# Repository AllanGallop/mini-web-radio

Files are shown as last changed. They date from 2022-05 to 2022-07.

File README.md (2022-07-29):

# Mini Web Radio

> Builders Guide now available on [Instructables](https://www.instructables.com/Mini-Web-Radio-ESP32/) !

Originally designed as a charity project, the MWR is a simple single-station battery powered internet radio. The design features a combined power-volume dial and 3.5mm headphone socket, utilising a 3D printed case and is based around:

* WeMos Lolin32 Lite (ESP32)
* MAX98357A I2S Dac Amplifier
* 18650 Lithium Battery

</br>

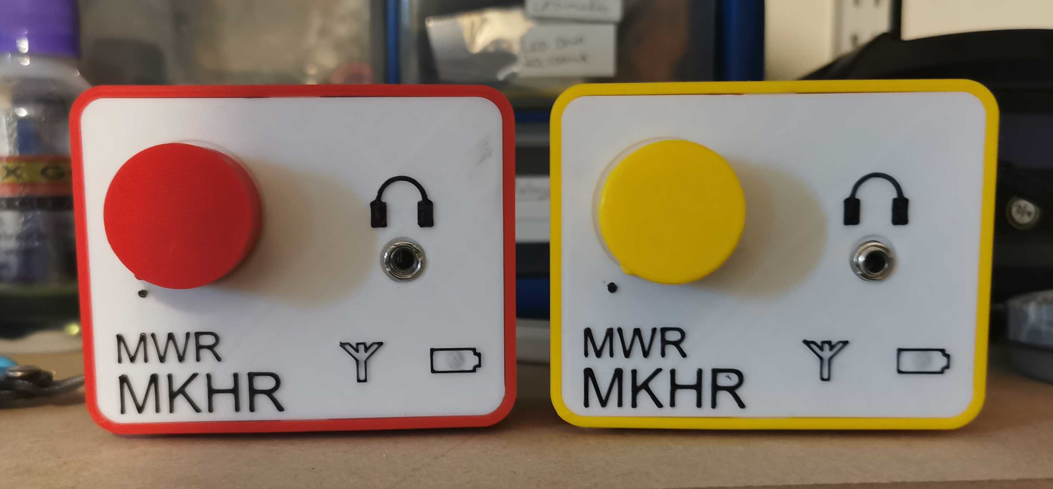
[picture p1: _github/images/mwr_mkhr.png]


</br>
  
## Documents

* [Build Guide](https://www.instructables.com/Mini-Web-Radio-ESP32/)

* [User Guide](Documentation/MWR_User_Guide.pdf)

* [Technical Guide](Documentation/MWR_Technical_Guide.pdf)

* [Bill Of Materials](Documentation/BOM.pdf)

</br>

## Configuration

The MWR has built-in browser based configuration which allows you to define the Hostname, Wireless network credentials and the playback URL.

> Enable Configuration mode

1. Switch Off MWR
2. Open Faceplate 
3. Install jumper (2.54mm) or short pins 13 and 15
4. Turn On MWR
5. Connect to `MWR-WIFI-SETUP` network
6. Remove Jumper
6. Navigate browser to `192.168.1.1`
7. Enter configuration Details and select `Save`
8. The MWR will automatically restart into radio mode and begin playback

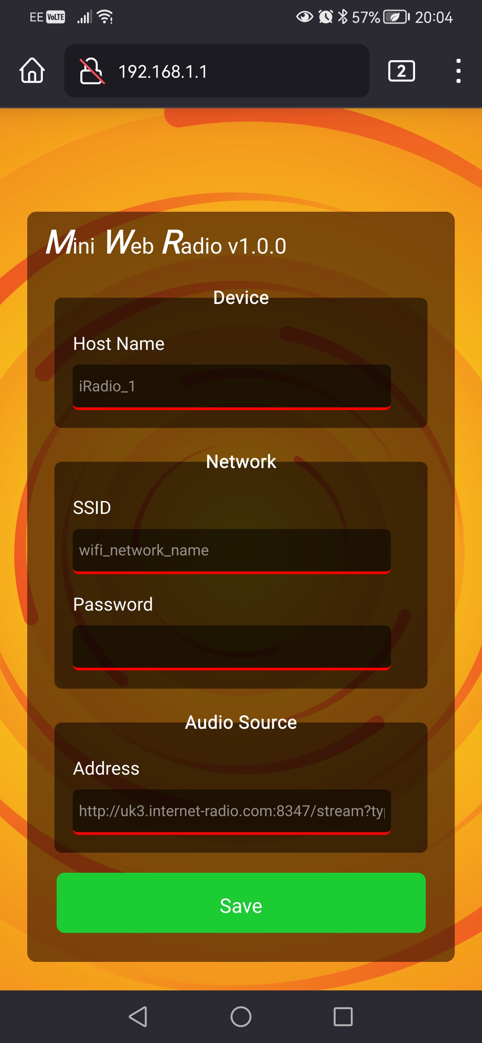
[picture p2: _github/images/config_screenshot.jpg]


## Firmware

Code for both the Arduino IDE and Plaform.io are included under the firmare directory

</br>

### Arduino IDE

> A more detailed guide for installing and setting up the Arduino IDE can be found on the [Wiki](https://github.com/AllanGallop/mini-web-radio/wiki/Arduino-IDE-(from-Scratch))

1. Download and install the following libaries:

    * [ESPAsyncWebServer](https://github.com/me-no-dev/ESPAsyncWebServer)

    * [ESP32-AudioI2S](https://github.com/schreibfaul1/ESP32-audioI2S)

2. Download and install the following Tools:

    * [ESPTool_py](https://github.com/me-no-dev/arduino-esp32fs-plugin/releases/)

3. Add the _Additional Board URL_ to the IDE properties (File > Preferences)

    ```https://raw.githubusercontent.com/espressif/arduino-esp32/gh-pages/package_esp32_index.json```

4. Using the _Board Manager_ add the board **esp32 - by Expressif Systems** (Tools > Board Manager)

5. Select the board: **Lolin32 Lite**

</br>

## Enclosure

Files for 3D printing the shell, face and dial are provided in the [CAD](CAD) directory. The enclosure uses a snaplock design to secure the face to the shell which can be difficult to lock into place initially, a small screw driver or spudger can make it easier to pry it open and closed.

**Print Settings:**

> These are just the settings that have worked for me, your milage may differ

* 0.4mm Nozzle
* 0.2mm Layer Height
* 5% Infill
* 1.75mm PLA+ Filament

</br>

## Schematic

![Schematic Preview](_github/images/schematic_preview.PNG)

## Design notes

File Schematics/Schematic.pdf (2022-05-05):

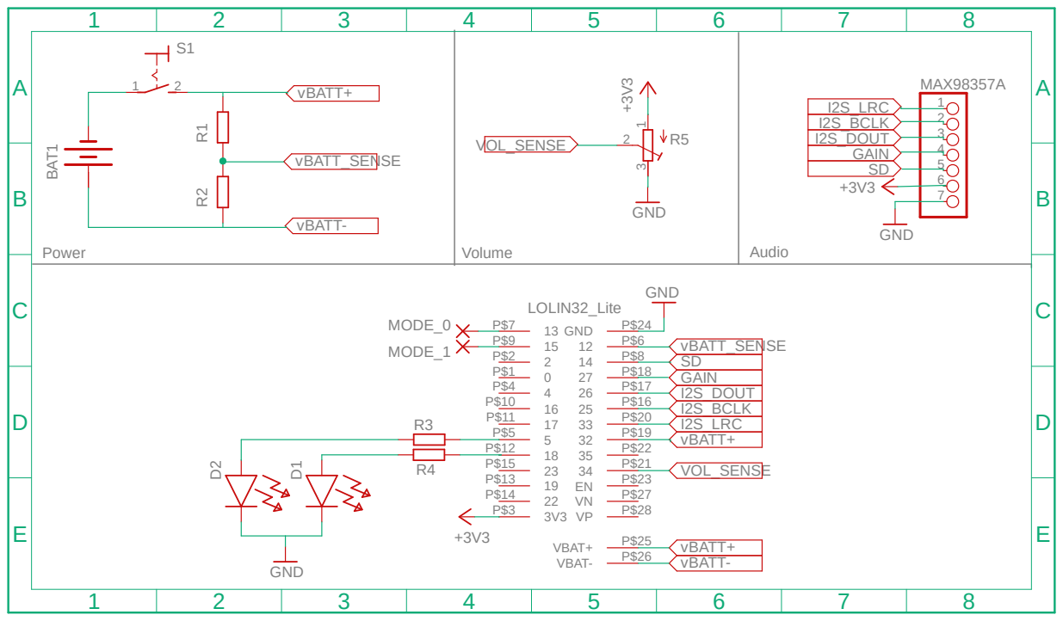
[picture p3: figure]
Power; Volume; Audio; GND; LOLIN32_Lite; vBATT-; vBATT+; GAIN I2S_DOUT I2S_BCLK; I2S_LRC; vBATT_SENSE; VOL_SENSE; GND ⁺³V³; I2S_BCLK I2S_DOUT GAIN SD +3V3; VBAT+; VBAT-; 7 MAX98357A BAT1; MODE_0; MODE_1

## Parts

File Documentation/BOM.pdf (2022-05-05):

Part | Description | Quantity | Price (avg) Total (est)
Microcontroller | WeMos Lolin32 Lite (or Clone) | 1 | 6.5 | 6.5
PCM Amplifier | Adafruit MAX98357A Module (or Clone) | 1 | 4.92 | 4.92
Battery | 18650 2500mAh | 1 | 4.89 | 4.89
Battery Holder | 18650 Compatible | 1 | 0.77 | 0.77
Volume Switch | 10KΩ Linear with SPST Switch. 6mm Dia Shaft | 1 | 0.75 | 0.75
Headphone Socket | 3.5mm TRRS Panel Mount | 1 | 0.99 | 0.99
LED | 3mm Red | 2 | 0.07 | 0.14
Resistor | 47KΩ 1/4W | 2 | 0.03 | 0.06
Resistor | 330Ω 1/4W | 2 | 0.03 | 0.06
Screw | M1.7 x 5mm Pan Head | 2 | 0.03 | 0.06
Screw | M2 x 5mm Flat Head | 1 | 0.03 | 0.03
Shell | PLA / PLA+ Filament (per Gram) | 39 | 0.021 | 0.819
Face | PLA / PLA+ Filament (per Gram) | 11 | 0.021 | 0.231
Dial | PLA / PLA+ Filament (per Gram) | 1.1 | 0.021 | 0.0231
Shell | PLA Unit Price (20 minimum) | 1 | - | 6.75
Face | PLA Unit Price (20 minimum) | 1 | - | 2.32
Dial | PLA Unit Price (20 minimum) | 1 | - | 1.89
Shell | PLA Unit Price (1 minimum) | 1 | - | 6.8
Face | PLA Unit Price (1 minimum) | 1 | - | 6
Dial | PLA Unit Price (1 minimum) | 1 | - | 6
Shell | PLA Unit Price (20 minimum) | 1 | - | 5.51
Face | PLA Unit Price (20 minimum) | 1 | - | 1.98
Dial | PLA Unit Price (20 minimum) | 1 | - | 0.77
Shell | ABS Unit Price (20 minimum) | 1 | - | 16.77
Face | ABS Unit Price (20 minimum) | 1 | - | 17.61
Dial | ABS Unit Price (20 minimum) | 1 | - | 16.74 | 51.12 | £70.29

3D Printed (CraftCloud3d.com)

Enclosure Total | Total
£18.80 | £37.97
Enclosure Total | Total
£8.26 | £27.43

3D Printed (PCBWay.com)

Enclosure Total | Total
£10.96 | £30.13

Vacuum Casting (PCBWay)

Enclosure Total | Total

Component Total

Enclosure Total | Total
£1.07 | £20.24

### Components

### Enclosure

3D Printed (Own Printer)

£19.17

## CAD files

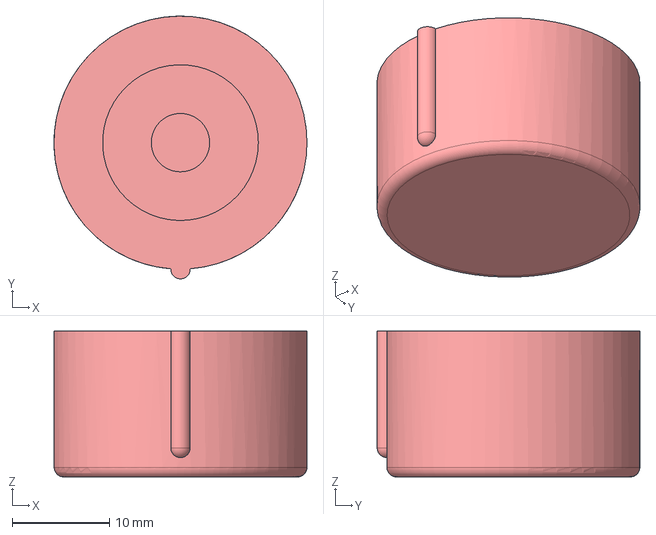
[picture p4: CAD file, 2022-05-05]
CAD/STEP/dial.step
26.0 x 27.0 x 15.0 mm

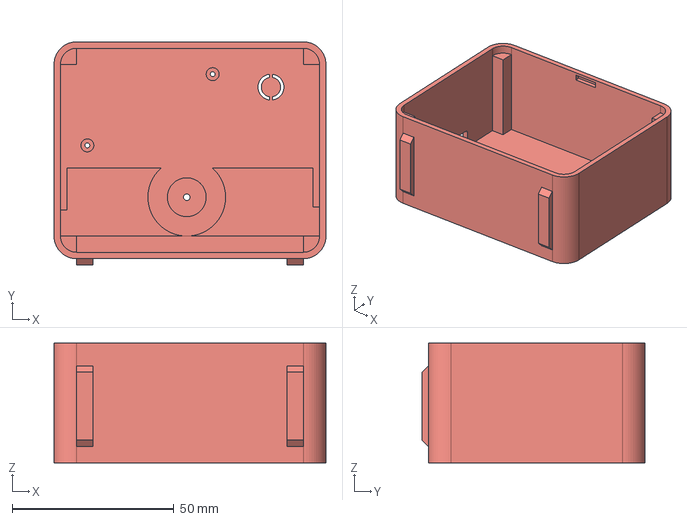
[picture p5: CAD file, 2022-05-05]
CAD/STEP/shell.step
84.0 x 69.0 x 37.0 mm

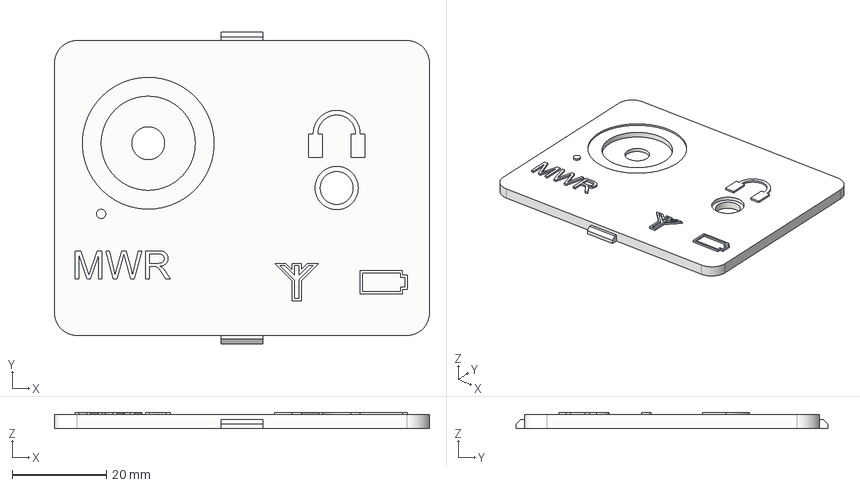
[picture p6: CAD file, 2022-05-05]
CAD/STEP/face.step
79.6 x 66.2 x 3.50 mm

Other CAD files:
CAD/STL/dial.stl
CAD/STL/face.stl
CAD/STL/shell.stl

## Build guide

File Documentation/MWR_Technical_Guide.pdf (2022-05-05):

# MWR

### Mini Web Radio

# Technical Guide

## Specification

- WeMOS Lolin32 Microcontroller
- 320Kb Memory
- 4Mb Flash Storage
- 802.11b/g/n Wi-Fi
- Li-Ion Battery Charger
- 18650 2500mAh Battery
- MAX9835A PCM Amplifier
- Class-D Amplifier
- 4W Output @ 4Ω

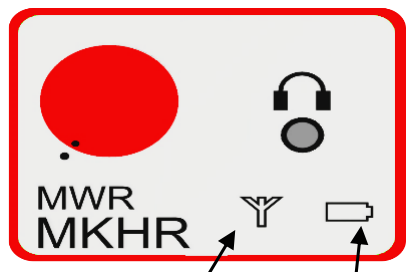
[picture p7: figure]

## Configuration

1. Switch Off MWR
2. Open MWR Shell
3. Install Jumper across labled pins 13 & 15 on the microcontroller
4. Power on MWR
5. Connect computer to Wi-Fi network “MWR-WIFI-SETUP”
6. Open web browser and navigate to 192.168.1.1
7. Enter a Hostname, SSID, Password and URL
8. Click Save and remove Jumper
9. Close MWR Shell

## Debug / Update

1. Connect USB Micro Cable to computer
2. Install Drivers, If needed
3. Configure UART to 8N1, 115200 Baud

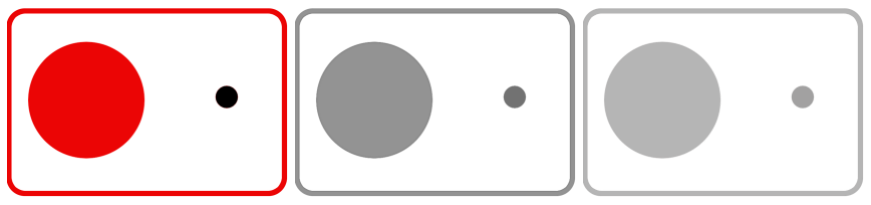
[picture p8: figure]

## Battery Charging

1. Make sure control knob is rotated to ON position
2. Insert USB Micro Cable and connect to a computer or wall charger (must be capable of 500mA [0.5A] or more)
3. Wait until battery status light reaches charged or Normal state
4. Rotate control knob to OFF position

Alternatively, battery cell may be removed and charged in a compatible charger.

## Status Indicators

Network Status

Indication | State
Off | Connected / Device Off
Flashing | Disconnected / Configuration Mode

Battery Status

Indication | State
Off | Device Off
Steady | >80 Capacity remaining
Slow Flashing | >30% Capacity remaining
Fast Flashing | <30% Capacity remaining, Recharge required
Short-Long Flash | Charging complete, device can be disconnected from charger
Network | Battery

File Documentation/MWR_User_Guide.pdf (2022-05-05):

# MWR

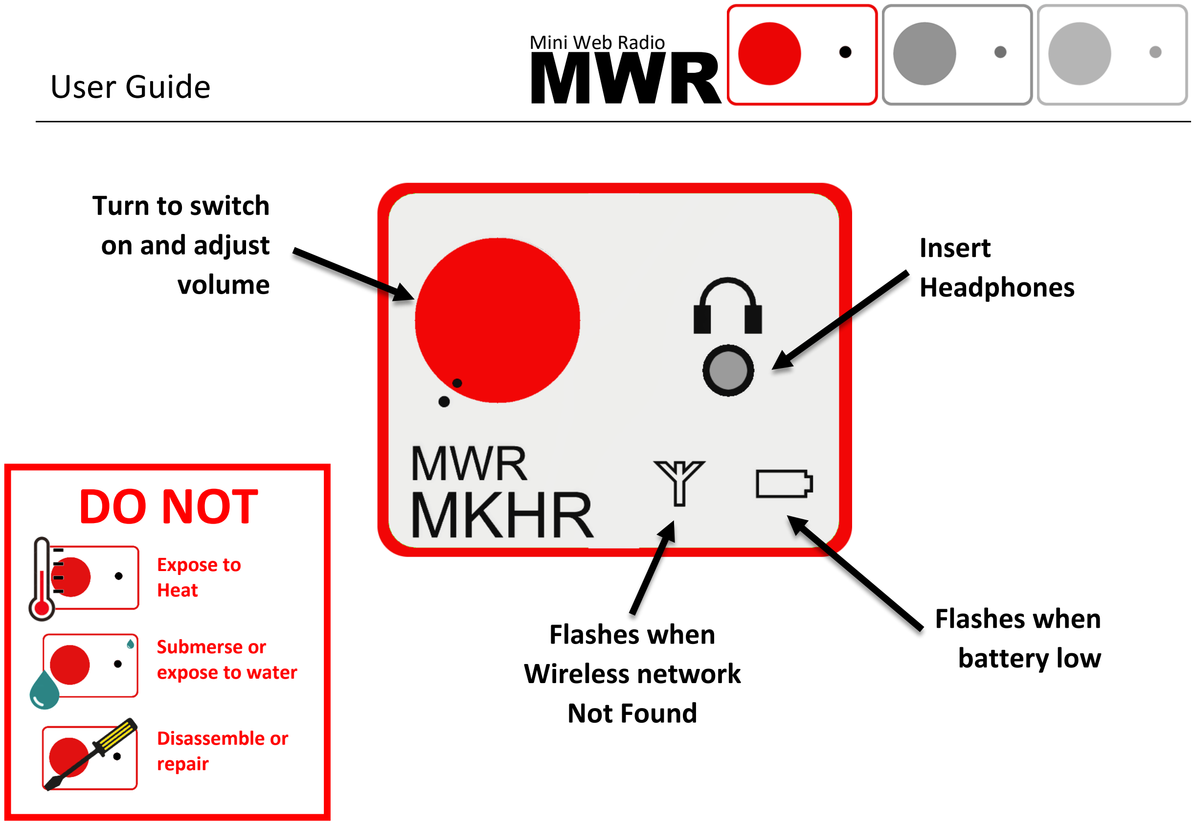
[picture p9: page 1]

Mini Web Radio

### User Guide

Expose to
Heat

Submerse or
expose to water

Disassemble or
repair

# DO NOT

Turn to switch
on and adjust
volume

Insert
Headphones

Flashes when
Wireless network
Not Found

Flashes when
battery low

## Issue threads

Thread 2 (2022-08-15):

Battery Management

AllanGallop, 2022-08-15:
As suggested by commenter on Hackaday:

* Deep sleep when battery level gets critical
* Syslog

My thoughts are deepsleep is great idea, although ESP loses power when switch is off, should implement in use cases where it has been left on unattended. I'd like future versions to use soft power so good to build from this.

Syslog would be nice, but AFAIK the hospital WiFi runs in isolation mode so would need to implement a public server off AWS, but would be great to have a grafana board available to them

AllanGallop, 2022-08-15:
Another feature I'd like to add is an audio prompt on low battery state, there should be enough space on device for small audio file

AllanGallop, 2022-08-18:
DW01 implementated as Tip on Instructables

Closed 2022-09-19.

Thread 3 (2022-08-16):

H/W Revision 2 - Wishlist

AllanGallop, 2022-08-16:
The next iteration will drop the Lolin32 in favour for a custom PCB based around the ESP32-WROOM-32E-N4

Current wishlist:

* TP4056 CC/CV charger
* DW01A undervoltage protection
* Replace potentiometer with Rotary encoder
* PCM5100APW i²S dual dac
* RGB led status indicators
* Headphones detection

AllanGallop, 2022-10-07:
Plans for v2 have been finalized

Closed 2022-10-07.

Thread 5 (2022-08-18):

Pinout / DAC Wiring

derFrickler, 2022-08-18:
Just finished my build, but i don't get any sound. Now i figured out there is something strange with the wiring of the CAD module.

The instructions say that the DAC module should be soldered with the GND Pins aligning.
Which leads to:
- SD 12
- Gain 14
- DIN 27
- BCLK 26
- LRC 25
-This is although what it looks lite on the pics: https://content.instructables.com/ORIG/FPW/Q9T0/L66H6K5D/FPWQ9T0L66H6K5D.jpg

But the Code defines these Pins as:
#define I2S_DOUT 26
#define I2S_BCLK 25
#define I2S_LRC  33
#define I2S_GAIN 27
#define I2S_SD 14

Which is shifted by one pin. Could you please clarify this.

Thanks a lot
       Johannes

AllanGallop, 2022-08-18:
Hi,
Apologies you are correct, we modified the design for the instructables slightly, moving the i2s module down by one pin which the code and schematic do not reflect yet. An update will be going up by end of the week to correct this and add deepsleep, but until then changing the pin definitions will facilitate getting it working:

SD = 12
Gain = 14
DIN = 27
BCLK = 26
LRC = 25

derFrickler, 2022-08-18:
YES, already got it working by changing the code.
#define I2S_DOUT 27
#define I2S_BCLK 26
#define I2S_LRC  25
#define I2S_GAIN 14
#define I2S_SD 12

BTW, the defined BATT pin is not used, analogread is hardcoded to pin 35.

Thanks
     Johannes

AllanGallop, 2022-08-18:
Repo has been updated to [v1.3.0](https://github.com/AllanGallop/mini-web-radio/releases/tag/v1.3.0) which will correct these issues

Closed 2022-08-18.

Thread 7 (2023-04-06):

cannot get response from 192.168.1.1

ranger2012, 2023-04-06:
i have logon to MWR-WIFI-SETUP
removed the jumper that connects pin 13 & 15

but  browser complain of
"no webpage was found  http://192.168.1.1/"
nothing comes out of the said address..

AllanGallop, 2023-04-06:
Hi,
Could you dump the output from the serial console from startup to point you try and connect please. Initially I would double check the data folder has been uploaded as this usually occurs when spiffs is empty

ranger2012, 2023-04-07:
i can see occasional  "inbound request" nothing else is happening..

attached is the serial monitor log..

5:34:06.329 -> RSSI:0
15:34:07.824 -> Battery:6.83
15:34:07.824 -> RSSI:0
15:34:09.345 -> Battery:6.83
15:34:09.345 -> RSSI:0
15:34:10.840 -> Battery:6.83
15:34:10.840 -> RSSI:0
15:34:12.338 -> Battery:6.83
15:34:12.391 -> RSSI:0
15:34:14.402 -> SPIFFS mounted successfully
15:34:14.402 -> 0
15:34:14.402 -> Battery:6.83
15:34:14.402 -> RSSI:0
15:34:14.402 -> Configuration Jumper Detected
15:34:14.402 -> Starting WiFi in AP Mode
15:34:15.877 -> Battery:6.83
15:34:15.877 -> RSSI:0
15:34:17.401 -> Battery:6.83
15:34:17.401 -> RSSI:0
15:34:18.923 -> Battery:6.83
15:34:18.923 -> RSSI:0
15:34:20.424 -> Battery:6.83
15:34:20.424 -> RSSI:0
15:34:21.908 -> Battery:6.83
15:34:21.908 -> RSSI:0
15:34:23.424 -> Battery:6.83
15:34:23.424 -> RSSI:0
15:34:24.926 -> Battery:6.83
15:34:24.926 -> RSSI:0
15:34:26.441 -> Battery:6.83
15:34:26.441 -> RSSI:0
15:34:27.934 -> Battery:6.83
15:34:27.934 -> RSSI:0
15:34:29.456 -> Battery:6.83
15:34:29.456 -> RSSI:0
15:34:30.959 -> Battery:6.83
15:34:30.959 -> RSSI:0
15:34:32.452 -> Battery:6.83
15:34:32.452 -> RSSI:0
15:34:33.945 -> Battery:6.83
15:34:33.945 -> RSSI:0
15:34:35.474 -> Battery:6.83
15:34:35.474 -> RSSI:0
15:34:36.982 -> Battery:6.83
15:34:36.982 -> RSSI:0
15:34:38.475 -> Battery:6.83
15:34:38.475 -> RSSI:0
15:34:40.129 -> Battery:6.83
15:34:40.129 -> RSSI:0
15:34:41.467 -> Battery:6.83
15:34:41.467 -> RSSI:0
15:34:42.976 -> Battery:6.83
15:34:42.976 -> RSSI:0
15:34:44.472 -> Battery:6.83
15:34:44.472 -> RSSI:0
15:34:46.019 -> Battery:6.83
15:34:46.019 -> RSSI:0
15:34:47.502 -> Battery:6.83
15:34:47.502 -> RSSI:0
15:34:49.014 -> Battery:6.83
15:34:49.014 -> RSSI:0
15:34:50.518 -> Battery:6.83
15:34:50.518 -> RSSI:0
15:34:52.026 -> Battery:6.83
15:34:52.026 -> RSSI:0
15:34:53.519 -> Battery:6.83
15:34:53.519 -> RSSI:0
15:34:55.019 -> Battery:6.83
15:34:55.019 -> RSSI:0
15:34:56.513 -> Battery:6.83
15:34:56.513 -> RSSI:0
15:34:58.015 -> Battery:6.83
15:34:58.015 -> RSSI:0
15:34:59.548 -> Battery:6.83
15:34:59.548 -> RSSI:0
15:35:01.024 -> Battery:6.83
15:35:01.024 -> RSSI:0
15:35:02.572 -> Battery:6.83
15:35:02.572 -> RSSI:0
15:35:04.052 -> Battery:6.83
15:35:04.052 -> RSSI:0
15:35:05.537 -> Battery:6.83
15:35:05.537 -> RSSI:0
15:35:07.078 -> Battery:6.83
15:35:07.078 -> RSSI:0
15:35:07.166 -> Inbound Request
15:35:08.577 -> Battery:6.83
15:35:08.577 -> RSSI:0
15:35:10.061 -> Battery:6.83
15:35:10.061 -> RSSI:0
15:35:11.581 -> Battery:6.83
15:35:11.581 -> RSSI:0
15:35:12.467 -> Inbound Request
15:35:13.092 -> Battery:6.83
15:35:13.092 -> RSSI:0
15:35:13.939 -> Inbound Request
15:35:14.609 -> Battery:6.83
15:35:14.609 -> RSSI:0
15:35:16.086 -> Battery:6.83
15:35:16.086 -> RSSI:0
15:35:16.433 -> Inbound Request
15:35:17.606 -> Battery:6.83
15:35:17.606 -> RSSI:0
15:35:17.714 -> Inbound Request
15:35:19.087 -> Inbound Request
15:35:19.087 -> Battery:6.83
15:35:19.087 -> RSSI:0
15:35:20.593 -> Battery:6.83
15:35:20.634 -> RSSI:0
15:35:22.123 -> Battery:6.83
15:35:22.123 -> RSSI:0
15:35:23.608 -> Battery:6.83

AllanGallop, 2023-04-07:
Looks like the data folder hasn't uploaded, have you tried uploading it again via Tools > ESP32 Sketch Data Upload in the Arduino IDE?

ranger2012, 2023-04-07:
i cannot find  arduino/tools/upload   opton.??

Sketch/upload or control U, dont have option to  select data
________________________________
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

AllanGallop, 2023-04-07:
It's part of EspTools package, instructions to install are in the Wiki:
https://github.com/AllanGallop/mini-web-radio/wiki/Arduino-IDE-(from-Scratch)

ranger2012, 2023-04-07:
I believe,  miss this step, uploading the  data folder into the spiff,   but how do i do that, there's no option n my arduino 2.04, or in arduino 1.8.19

Thanks,

________________________________
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

AllanGallop, 2023-04-07:
I don't believe there is a version of esptools for IDE 2.x yet, but certainly is for 1.8.x

Full instructions can be found on their [GitHub ](https://github.com/me-no-dev/arduino-esp32fs-plugin)

ranger2012, 2023-04-07:
All working now, works like a charm..

Thank you very much

Closed 2023-04-07.

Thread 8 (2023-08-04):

Powered by micro USB without batteries.

mikronwfh, 2023-08-04:
Hi! All I did was remove line 49 from the script.

1. What can I do next to use micro USB power only. I will never use battery power.
2. Where to connect the potentiometer in this case?
3. Can speakers above 3W be inefficient and will play unstable thanks to the radio?

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

AllanGallop, 2023-08-04:
Hi,
I've created a [new branch](https://github.com/AllanGallop/mini-web-radio/tree/no-battery) with a modified firmware INO file and a schematic change (see the readme). This removes the need for the battery LED (R3 and D2) along with omitting the battery sense circuit (R1/R2) and instead connecting the switch between the 3v3 rail and GPIO pin 33 to sleep/wake the ESP32.

AllanGallop, 2023-08-04:
To answer your questions more directly:

1. Use the new branch and modification to remove the battery and it's associated parts
2. The potentiometer remains unchanged however the switch side of it connects directly between 3v3 and Pin 33
3. The maximum output of the I²S module is 3W so if using a 4Ω speaker you want it to have a power rating equal or greater than 3W (>1.5W for an 8Ω speaker). If attempting to drive an exceptionally large speaker the module may have issues actuating the voice coil

mikronwfh, 2023-08-04:
thank you very much.  I'll let you know how it works when I test it :)

mikronwfh, 2023-08-06:
Can I connect the aux socket instead of the speaker to output the sound to the receiver and amplifier?

AllanGallop, 2023-08-06:
You can but bare in mind the output is mono not stereo, if that's not an issue you can bridge the channels to drive a stereo system. If it needs to be line level then you'd need to put in a voltage divider between the audio output and line in such as this:
https://www.circuitlab.com/editor/#?id=x5r3s4exfgzp

mikronwfh, 2023-08-06:
> Hi, I've created a [new branch](https://github.com/AllanGallop/mini-web-radio/tree/no-battery) with a modified firmware INO file and a schematic change (see the readme). This removes the need for the battery LED (R3 and D2) along with omitting the battery sense circuit (R1/R2) and instead connecting the switch between the 3v3 rail and GPIO pin 33 to sleep/wake the ESP32.

I understand that there is no option to use the microUSB that we have on the ESP32 board to power the radio? I have to make a new one and connect it to 3v3 and 33?

mikronwfh, 2023-08-06:
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

AllanGallop, 2023-08-07:
> I just copied the new MWR.ino file and the rest remains unchanged? I have this message right now. 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

My mistake, it should read as ``` if(digitalRead(POWER_SW) == LOW)```, I have updated the branch to reflect this. Yes the remaining structure is unchanged, if you remove the extra ```=``` from the if statement it should compile

mikronwfh, 2023-08-07:
I'll check it and let you know. Meme also another problem. After installing IDE 2.0, I had ESP32 visible immediately under COM when I connected it to USB. Now I threw out all arduino ide directories and installed v 1.8.16 again and in Tool >> Port I have inactive. Nothing happens in the device manager either when I connect the ESP32. Fix it ASAP.

AllanGallop, 2023-08-07:
I cannot comment on issues regarding the Arduino IDE or ESP libary, nor fix them as I am not a contributor or owner of those projects.

mikronwfh, 2023-08-07:
>
Done and it works. I replaced the USB cable with another one.

mikronwfh, 2023-08-07:
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

Not too many exits? There is not so much on my WEMOS ESP32.
So I don't know if I'm doing it right. I understand that the microUSB on the WEMOS ESP32 board will supply power after switching it on with a potentiometer? Should I put a microUSB between the GPIO and the potentiometer?

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

mikronwfh, 2023-08-07:
I do not know how to connect the potentiometer with the entire ESP32 system in the new version. Instead of a battery, I have a USB cable with two wires +/- prepared. Only USB is 5V, and in the old scheme with the battery it is 3.7V. A new scheme for connecting the potentiometer with ESP32 would make it much easier for me. And should I have the power supply from the ESP32 board as it is in the old scheme, or can I use the microUSB power supply?

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

AllanGallop, 2023-08-08:
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

Hi, hopefully this clears it up for you. I've omitted the additional parts for simplicity

mikronwfh, 2023-08-08:
the potentiometer has 5 legs.  if one is bridged, there are 4 remaining. and in the diagram I have 3 connections going to the potentiometer.

AllanGallop, 2023-08-08:
You have a switched potentiometer which contains both a switch and potentiometer, the two pins on the back are the switch, the remaining 3 tabs on the side are the potentiometer; with knob facing you they are left connects to ground, center goes to pin 34, and right to 3v). you may bridge one of the switch pinsto the right (3v) leg to reduce need for multiple 3v wires with the remaining switch pin connected to pin 33

mikronwfh, 2023-08-08:
First of all, thank you very much for your commitment to running.
I just finished my project according to your idea. :) Wow! It works! :))

https://youtu.be/Dh8_dGSo-cg

One thing that puzzles me is whether the diode on the ESP32 board (LED charging bat) should be lit after turning off the power using the potentiometer? This blue diode on 5 GPIO goes out, but the factory one on the board quickly pulses with blue light.

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

Closed 2023-08-04.

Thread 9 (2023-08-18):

Is the Max fine for headphones?

olup, 2023-08-18:
This DAC is usually paired with a speaker, is that working all the same with headphones ?

AllanGallop, 2023-08-19:
It works, but using class D is not overly efficient and it's mono output so not exactly high fidelity but for the original application of project it's fine.

I'll be releasing the plans for version 2 very soon which uses a PCM102a and a TD1308 if you prefer a headphone only design with stereo

olup, 2023-08-19:
I am building a product that will offer speaker and headphone. It's going to be mono anyway. Using just one i2s amp would be a good design. Is power consumption the only drawback then ? How bad is it ?

AllanGallop, 2023-08-19:
Sorry I should clarify, the use of a 3W class D amp solely for headphones makes a little less sense as they don't need all that much to drive them and can be more sensitive to distortion, for a small speaker it's more ideal, likewise if using both. Class D is more power efficient but lacks fidelity of say a class AB, however that doesn't really matter too much for this projects application (44.1khz mp3 stream) and the efficiency benefits battery life.

olup, 2023-08-19:
My bad, I didn't catch well. So in my case, a 44.1 mono mp3 player with speaker or optionnal headphone output, I understand the max makes actually good sense. I don't target hifi, this is mainly stories and podcasts.

Thanks for your answers.

Closed 2023-08-19.

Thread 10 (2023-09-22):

Application of PCM5102

mikronwfh, 2023-09-22:
I bought Dell ax510 speakers that are powered by 12v 1A and I wanted to ask if, after using a 12v 2 amp power supply,

I will be able to power esp32 as well. I also want to ask about throwing away the potentiometer

and reprogramming so that the ESP 32 board, my internet radio, always works with the maximum set value after turning it on.
volume because I will adjust the volume from the loudspeaker. Please remember that this time I will use the pcm5102 amplifier

AllanGallop, 2023-09-25:
I don't see why not, the nominal current draw for a MWR2 which uses a PCM5201PWR and is around 100mA @ 3.3v (~330mW) so even with losses from buck conversion a 1A supply should be more than sufficient. You can programmatically specificy the output volume though the values are a bit ambiguous so I would recommend adding a trim pot to prevent clipping.

mikronwfh, 2023-10-06:
I'm trying to do it right now, but I don't think I know what it's supposed to look like. Can you somehow help with the code? And the diagram for PCM5102?

AllanGallop, 2023-10-06:
Functionally they are both the same as they use I²S protocol so it should be as simple as matching the signals to the correlated pins of the module.

To maintain a volume without the potentiometer the lowest effort programmatically would be to edit line 83 of the INO with a fixed integer instead of the function call ie  ``` mRadio.setVolume(22);```

mikronwfh, 2023-10-07:
I've already managed. On PCM5102, SCK should be provided on GND. On ESP32, 12 and 14 remain free.

Now I would like to power ESP32 - 5V in some way directly from the PCB because I do not have that many cables with a USB - C plug

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

mikronwfh, 2023-10-07:
I'm still thinking about the potentiometer. Is it possible to change to digital? The standard one is quite large and unattractive compared to the entire design. Or maybe if not digital, then analog, only in smaller sizes. But what kind?

mikronwfh, 2023-11-12:
In my home WiFi network, I observe a case where the radio disconnects from the URL address of the radio station I am listening to.
I check the connection for my radio in the winbox of my mikrotik and it is connected to the router. What modification of the code could check whether the connection stream to the radio station's server has not been interrupted, because the connection to the router via WiFi is still functional and working.

AllanGallop, 2023-11-12:
ultimately there is not a lot that can be done as several factors are involved when it comes to drop outs on the network side such as bandwidth, contention, bitrate that do not necessarily fall under the conditions of a WiFi disconnect event.

I have observed that some of the ESP32 clones have less than stellar antenna design but even on the official expressif units it's still a comprise of size and performance.

In theory you could do something with the RSSI method but any static values would vary between boards and location. The current code will attempt to reconnect if the disconnect condition is met

Closed 2023-09-25.

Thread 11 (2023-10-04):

Removing the amplifier from ESP32

mikronwfh, 2023-10-04:
Should I correct the code if I completely give up the DAC and want to directly connect MC to ESP32? I would like the radio station to be heard immediately through my receiver without using Max98357?

AllanGallop, 2023-10-06:
What is MC in this context?

Closed 2024-07-07.

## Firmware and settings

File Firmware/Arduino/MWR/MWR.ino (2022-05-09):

#include <Arduino.h>
#include <SPIFFS.h>
#include "mwr_radio.h";
#include "mwr_config.h";

// Pin Definitions
#define I2S_DOUT 26
#define I2S_BCLK 25
#define I2S_LRC  33
#define I2S_GAIN 27
#define I2S_SD 14
#define LED_BATT 5
#define LED_WIFI 18
#define VOL 34
#define BATT 12
#define MODE_0 13
#define MODE_1 15

// Initalise Libaries
MWConfig mConfig;
MWRadio mRadio;

// Initialise Battery Task
TaskHandle_t ChckBatTsk;

int mode = 0;   // Mode State

void setup() {
  // Start Serial for debugging
  Serial.begin(115200);
  pinMode(LED_BATT,OUTPUT);
  pinMode(LED_WIFI,OUTPUT);

  // Start SPIFFS
  if (!SPIFFS.begin(true)) {
    Serial.println("An error has occurred while mounting SPIFFS");
  }
  Serial.println("SPIFFS mounted successfully");

  // Create Battery Task
  xTaskCreatePinnedToCore(CheckBattery,"ChckBatTsk",10000,NULL,0,&ChckBatTsk,0);

  // Detect operating mode
  mode = mConfig.detectMode(MODE_0,MODE_1);
  if(!mode){   
    // Start into Config mode
    mConfig.apMode();
    while (WiFi.status() != WL_CONNECTED){flashLED(LED_WIFI,150);delay(500);}
  }else{      
    // Start into Radio mode
    mConfig.stMode();
    while (WiFi.status() != WL_CONNECTED){flashLED(LED_WIFI,150);delay(500);}
    WiFi.onEvent(WiFiStationDisconnected, SYSTEM_EVENT_STA_DISCONNECTED);
    // Initalise Audio
    mRadio.init(I2S_DOUT, I2S_BCLK, I2S_LRC, I2S_GAIN, I2S_SD);
    // Get and Set Station URL
    String url = mConfig.readUrlFromFile();
    mRadio.setStation(url);
  }
}

void loop() {
  if(mode){
   mRadio.setVolume(getVolume());
   mRadio.play();   
  }
}

// Get volume state, mapped 1-20
int getVolume()
{
  return map(analogRead(VOL), 0, 4095, 1, 20);
}

// Check Battery Level
void CheckBattery( void * parameter) {
  float voltage = 0;
  int timer = 200;
  for(;;) {
    if(timer >= 200){ voltage = ((float)analogRead(35) / 4095) * 3.3 * 2 * 1.035; timer = 0; }
      if(voltage > 4) {
        digitalWrite(LED_BATT,HIGH); delay(100); digitalWrite(LED_BATT,LOW); delay(100);
        digitalWrite(LED_BATT,HIGH); delay(300); digitalWrite(LED_BATT,LOW); delay(100);
      }else{
        if(voltage > 3.7){
          digitalWrite(LED_BATT,HIGH);    // Normal Range
          delay(1000);
        }else{
          if(voltage > 3.5){              // Lower End
            flashLED(LED_BATT,500);
          }else{                   
            flashLED(LED_BATT,150);       // Low or Anonomly
          }
        }
      }
    timer++;
    Serial.print("Battery:");
    Serial.println(voltage);
    Serial.print("RSSI:");
    Serial.println(WiFi.RSSI());
  }
}

// Flash an LED
void flashLED(int LED, int SPEED)
{
  digitalWrite(LED,HIGH);
  delay(SPEED);
  digitalWrite(LED, LOW);
  delay(SPEED);
}


void WiFiStationDisconnected(WiFiEvent_t event, WiFiEventInfo_t info){
  Serial.println("Disconnected from WiFi access point");
  Serial.print("WiFi lost connection. Reason: ");
  Serial.println(info.disconnected.reason);
  Serial.println("Trying to Reconnect");
  WiFi.reconnect();
}

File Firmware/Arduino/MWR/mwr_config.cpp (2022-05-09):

#include <Arduino.h>
#include "FS.h"
#include <SPIFFS.h>
#include <ESPAsyncWebServer.h>
#include <AsyncTCP.h>
#include "mwr_config.h"

const char* PARAM_INPUT_1 = "host";
const char* PARAM_INPUT_2 = "ssid";
const char* PARAM_INPUT_3 = "pass";
const char* PARAM_INPUT_4 = "url";

String host;
String ssid;
String pass;
String url;

const char* ssidPath = "/ssid.txt";
const char* passPath = "/pass.txt";
const char* hostPath = "/host.txt";
const char* urlPath = "/url.txt";

IPAddress localIP(192,168,1,1);
IPAddress localGateway(192,168,1,1);
IPAddress subnet(255,255,255,0);

AsyncWebServer server(80);

MWConfig::MWConfig()
{}

int MWConfig::detectMode(int source, int sink)
{
  pinMode(source,OUTPUT);
  pinMode(sink,INPUT_PULLUP);
  delay(1);
  digitalWrite(source,LOW);
  delay(1);
  int mode = digitalRead(sink);
  Serial.println(mode);
  delay(1);
  digitalWrite(source,LOW);
  if(!mode){ Serial.println("Configuration Jumper Detected"); }
  return mode;
}

void MWConfig::apMode()
{
  Serial.println("Starting WiFi in AP Mode");
  WiFi.disconnect();
  WiFi.softAPConfig(localIP,localGateway,subnet);
  WiFi.softAP("MWR-WIFI-SETUP", NULL);

    // Web Server Root URL
    server.on("/", HTTP_GET, [](AsyncWebServerRequest *request){
      Serial.println("Inbound Request");
      request->send(SPIFFS, "/index.html", "text/html");
    });
    
    server.serveStatic("/", SPIFFS, "/");
    
    server.on("/", HTTP_POST, [this](AsyncWebServerRequest *request) {
      int params = request->params();
      for(int i=0;i<params;i++){
        AsyncWebParameter* p = request->getParam(i);
        if(p->isPost()){
          if (p->name() == PARAM_INPUT_1) {
            host = p->value().c_str();
            writeFile(SPIFFS, hostPath, host.c_str());
          }
          // HTTP POST ssid value
          if (p->name() == PARAM_INPUT_2) {
            ssid = p->value().c_str();
            // Write file to save value
            writeFile(SPIFFS, ssidPath, ssid.c_str());
          }
          // HTTP POST pass value
          if (p->name() == PARAM_INPUT_3) {
            pass = p->value().c_str();
            // Write file to save value
            writeFile(SPIFFS, passPath, pass.c_str());
          }
          // HTTP POST gateway value
          if (p->name() == PARAM_INPUT_4) {
            url = p->value().c_str();
            // Write file to save value
            writeFile(SPIFFS, urlPath, url.c_str());
          }
        }
      }
      request->send(200, "text/plain", "Done. "+host+" will restart");
      delay(3000);
      ESP.restart();
    });
    server.begin();
}

void MWConfig::stMode()
{
  Serial.println("Starting WiFi in Station Mode");
  host = readFile(SPIFFS, hostPath);
  ssid = readFile(SPIFFS, ssidPath);
  pass = readFile(SPIFFS, passPath);
  WiFi.disconnect();
  WiFi.mode(WIFI_STA);
  WiFi.setHostname(host.c_str());
  Serial.print("Connecting to: ");
  Serial.println(ssid);
  if(pass == NULL| pass.isEmpty()){
    Serial.println("with no password");
    WiFi.begin(ssid.c_str());
  }else{
    WiFi.begin(ssid.c_str(), pass.c_str());
  }
}

String MWConfig::readUrlFromFile()
{
  return readFile(SPIFFS, urlPath);
}

// Read File from SPIFFS
String MWConfig::readFile(fs::FS &fs, const char * path){
  Serial.printf("Reading file: %s\r\n", path);

  File file = fs.open(path);
  if(!file || file.isDirectory()){
    Serial.println("- failed to open file for reading");
    return String();
  }
  
  String fileContent;
  while(file.available()){
    fileContent = file.readStringUntil('\n');
    break;     
  }
  return fileContent;
}

// Write file to SPIFFS 
void MWConfig::writeFile(fs::FS &fs, const char * path, const char * message){
  Serial.printf("Writing file: %s\r\n", path);

  File file = fs.open(path, FILE_WRITE);
  if(!file){
    Serial.println("- failed to open file for writing");
    return;
  }
  if(file.print(message)){
    Serial.println("- file written");
  } else {
    Serial.println("- frite failed");
  }
}
